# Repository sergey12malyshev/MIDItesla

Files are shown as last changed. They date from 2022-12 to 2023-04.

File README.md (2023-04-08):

# MIDItesla
MIDI Tesla Coil Controller

Программно-аппаратный проект музыкальной катушки Тесла построенной по топологии SSTC полумост. Состоит из непосредсвенно катушки Тесла, MIDI-контроллера состоящего из прерывателя bsvi на Atmega8 и микрокомпьютера Raspberry Pi 3B генерирующего MIDI мелодии.

Hardware-software project of a musical Tesla coil built on the SSTC half-bridge topology. It consists of a Tesla coil itself, a MIDI controller consisting of a bsvi interrupter on an Atmega8 and a Raspberry Pi 3B microcomputer that generates MIDI melodies.

  

 

## Программная реализация (Software) ##
Представляет собой python-скрипты выполняющиеся на Raspberry Pi B3:
* **MainMidi.py** - python скрипт генерирующий MIDI последовательности в serial-порт raspberry pi. Осуществляет переключение мелодий путём опроса кнопки.
* **lcd1602.py** - python скрипт осуществляющий вывод информации о состоянии raspberry на LCD экран 1602 (в проекте опционален).
* **runScripts.sh** - исполняемый bash скрипт необходим для запуска скриптов MainMidi.py и lcd1602notButton.py в скрытом режиме при старте системы.
Запуск скрипта runScripts.sh прописан в системном файле crontab. Для открытия файла необходимо набрать:
```bash
crontab -e
```
В файле добавить запись:
```bash
@reboot /home/pi/Desktop/runScripts.sh
```
Второй вариант запуска (вместо **runScripts.sh**) 
В crontab файле добавить запись:
```bash
@reboot python3 /home/pi/Desktop/MainMidi.py &
@reboot python3 /home/pi/Desktop/lcd1602.py &
```
## Аппаратная реализация (Hardware) ##
Cтруктурная схема всего комплекса:



Cхема электрическая принципиальная трансформатора Тесла(приведена в директории shemes):



Схема подключения MIDI OUT и схема подключения LCD 1602:

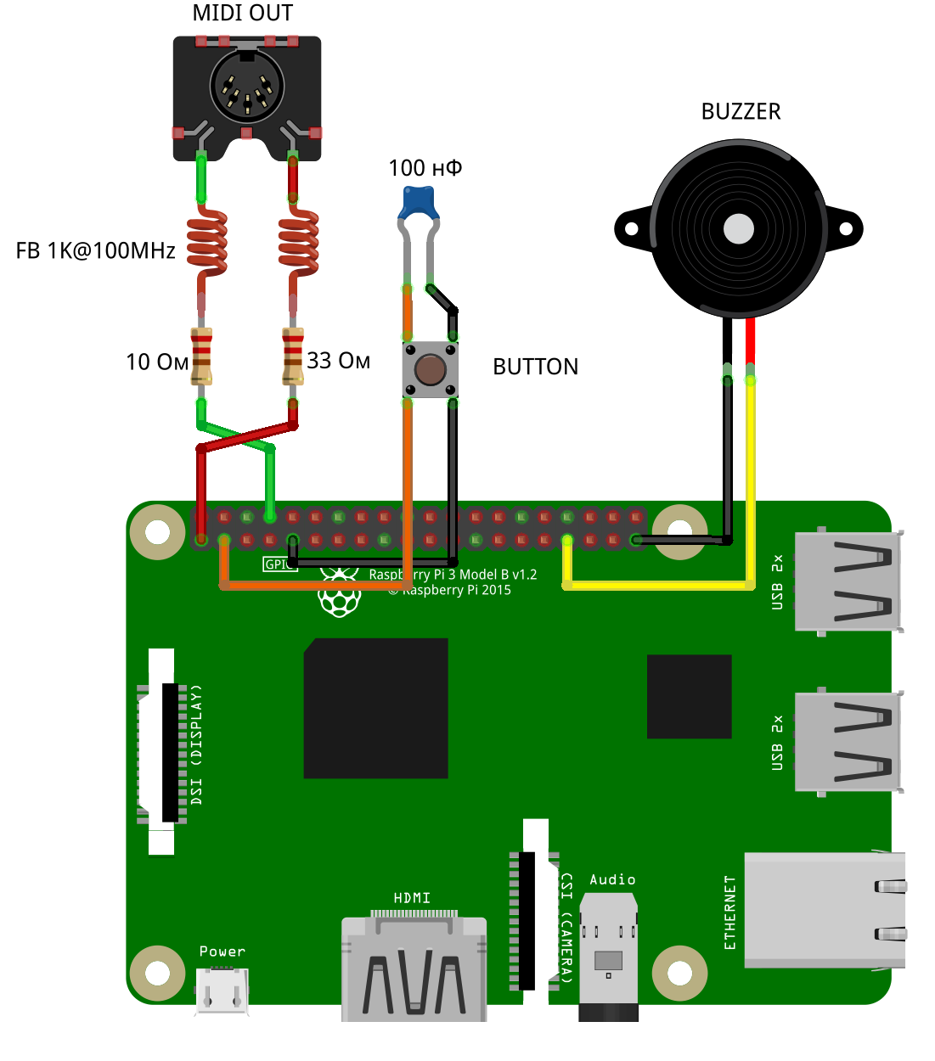
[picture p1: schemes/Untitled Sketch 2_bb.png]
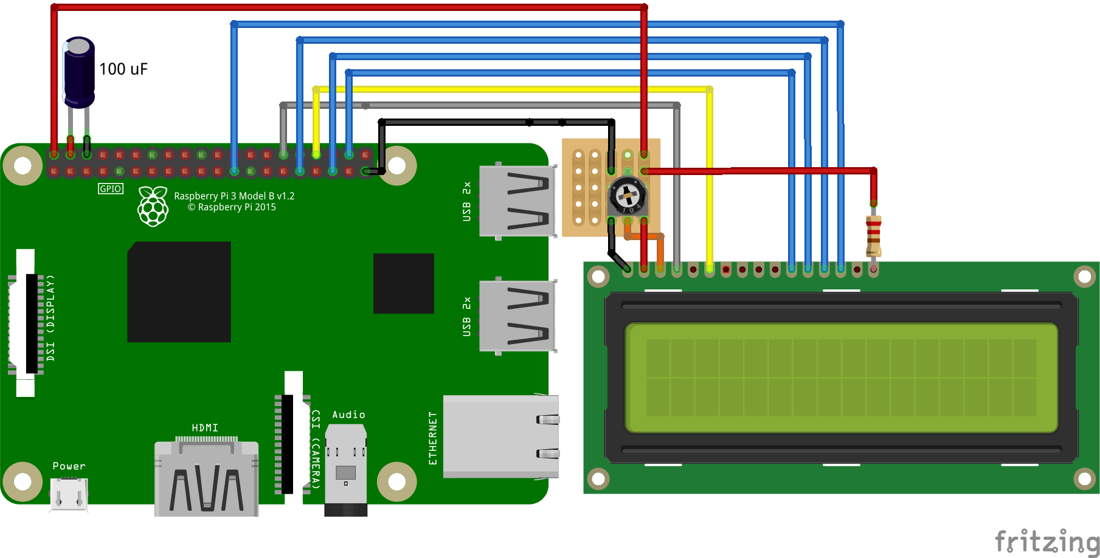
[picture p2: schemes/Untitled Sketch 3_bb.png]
     

## Создание MIDI-мелодий (Creating MIDI tunes) ##
Написание MIDI-мелодий происходит непосредственно в файле **MainMidi.py** используя функцию *playNote(note, timeOn, timeOff)*, где note - номер ноты от 36 до 71;  timeOn - время звучания в секундах; timeOff - время паузы в секундах (нет звучания). Соотношение нота-номер и нота-время приведено на рисунке:



Доступные мелодии:
- Gershon Kingsley - Popcorn
- Super Mario Song
- Mortal Kombat Theme Song
- Valces Dogs melody
- Star Wars - The Imperial March
- Mission impossible theme
- The Prodigy - Omen

## Видео работы (Demo video of work) ##
https://www.youtube.com/shorts/8kgel5WYpHc

https://youtu.be/iuJQ5y0yN18

## Полезная информация (Helpful information)
* https://bsvi.ru/preryvatel-dlya-drsstc/ - прерыватель использованный для проекта
* https://bsvi.ru/malleus-maleficarum-apgrejd/ - дизайн SSTC
* http://teslacoil.ru/katushki-tesla/tranzistornyie-katushki/polumostovaya-sstc/  - дизайн SSTC
* https://stevehv.4hv.org/SSTC5.htm  - дизайн SSTC
* https://kaizerpowerelectronics.dk/tesla-coils/sstc-design-guide/ - советы по конструкции SSTC
* https://teslafon.ru/techno/calcs - калькулятор для расчёта резонансного трансформатора
* https://www.loneoceans.com/labs/ud27/ - Universal DRSSTC Tesla Coil Driver 2.7 Rev C
* https://www.osaelectronics.com/learn/setting-up-raspberry-pi-for-midi/ - работа с midi на raspberry
* https://www.midi.org/specifications-old/item/midi-din-electrical-specification - спецификация аппаратного уровня MIDI
* http://flyback.org.ru/viewtopic.php?p=4425021#4425021 - ссылка на форум по данной конструкции
* https://pinout.xyz/ - The Raspberry Pi GPIO pinout guide

## Code style
PEP8

### Удалённое управление (Remote control)
VNC Viewer: http://wiki.amperka.ru/rpi:installation:vnc

Для автоматического запуска VNC запустить скрипт **runVNC.sh**

### Параметры резонансного трансформатора ###
Емкость тороида: 6 пФ

Индуктивность первичной обмотки: 2.94 мкГн

Индуктивность вторичной обмотки: 32901 мкГн

Количество витков вторичной обмотки: 840

Емкость вторичной обмотки: 5.8 пФ

Общая емкость вторичного контура: 11.8 пФ

Резонансная частота катушки тесла: 255.4 кГц

Доп. информация для искушенных:

Длина волны: 1565 м

Длина провода вторичной обмотки (фактическая): 290 м

Длина провода 1/4 длины волны (расчетная): 391.25 м

Процент совпадения фактической и расчетной длин: 74.1 %

Сопротивление первичной обмотки:
xL = 2 * ПИ * F * L = 2ПИ * 255.4 кГц * 2.94 мкГн = 4,73 Ом

Ток первичной обмотки:
Ipeack = U/xL = (310 В/2)/4,73 Ом =  32,8 А (выбрал ключи W45NM60 - 45 А)

### TODO
Переработать проект под чтение готовых файлов .mid

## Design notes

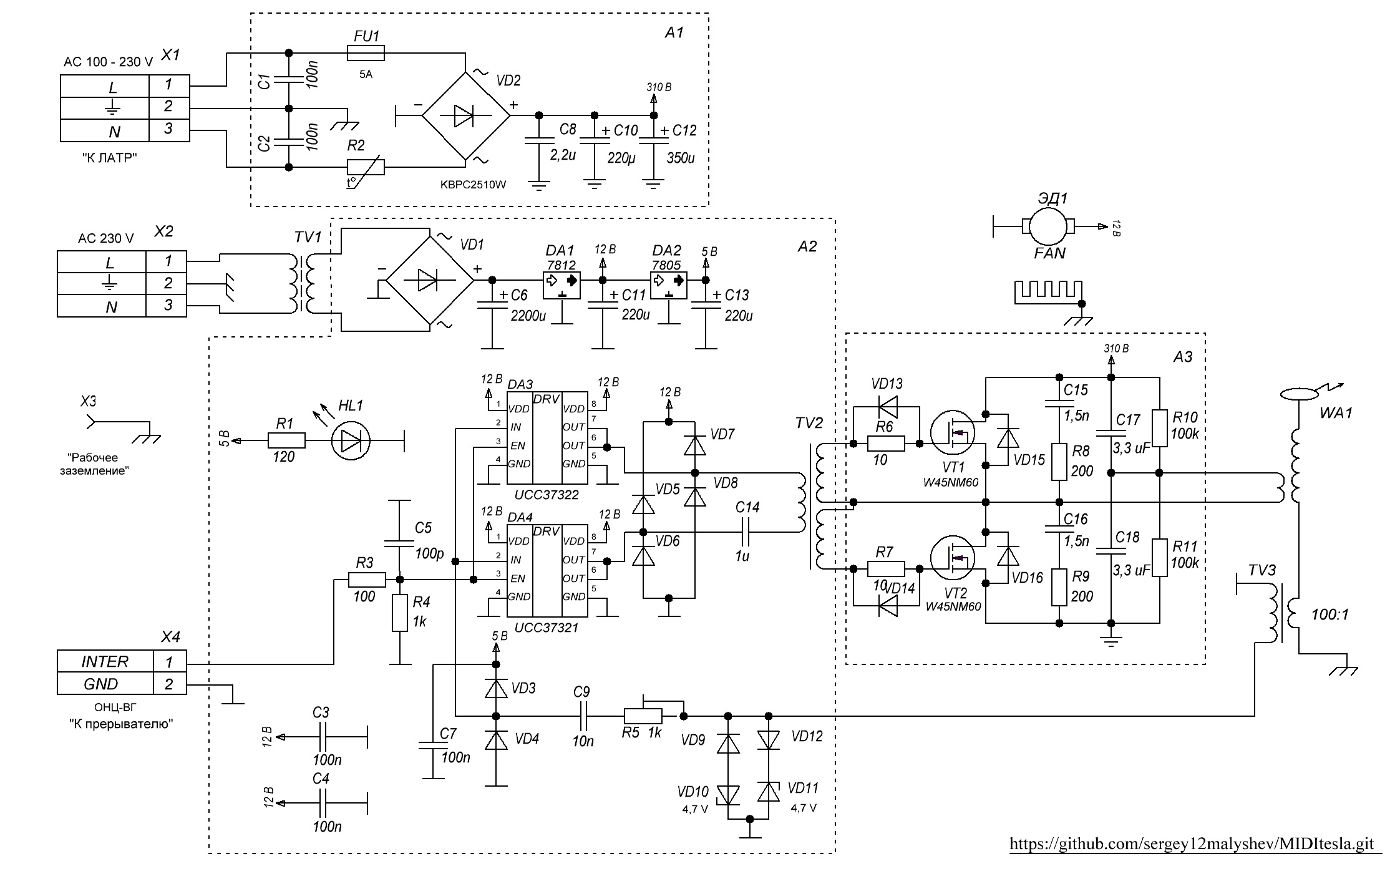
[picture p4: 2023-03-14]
images/Схема принципиальная КТ (4).jpg

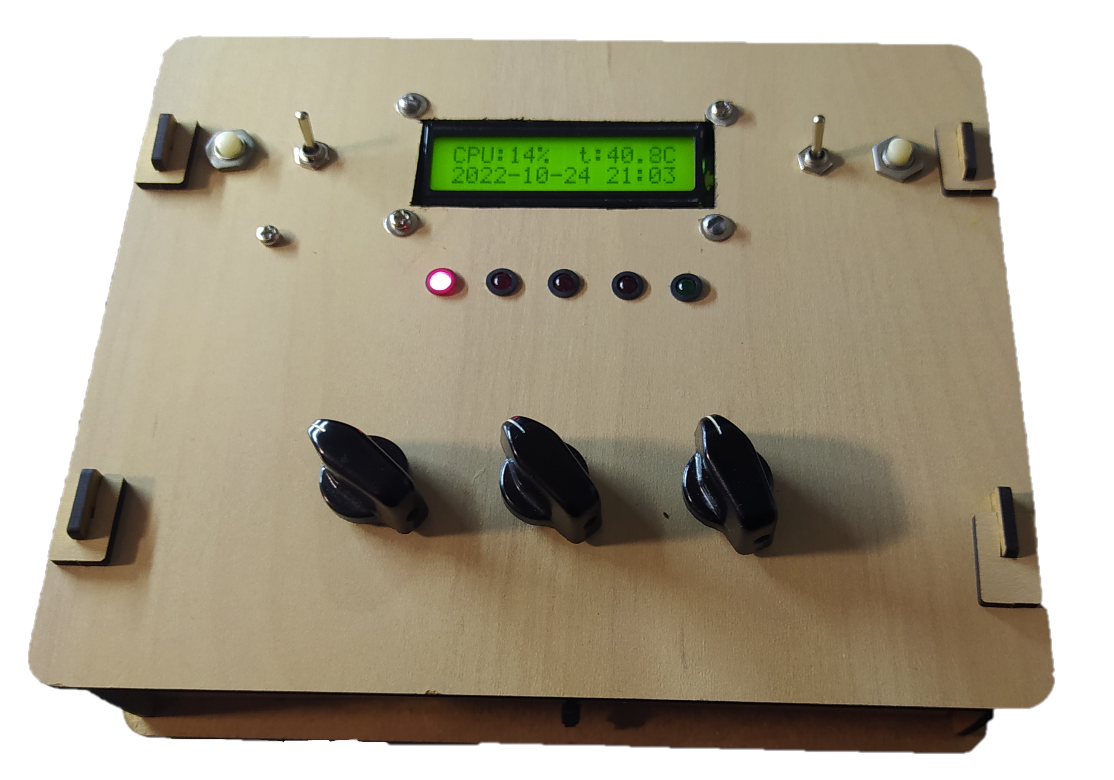
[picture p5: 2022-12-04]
images/Пульт.jpg

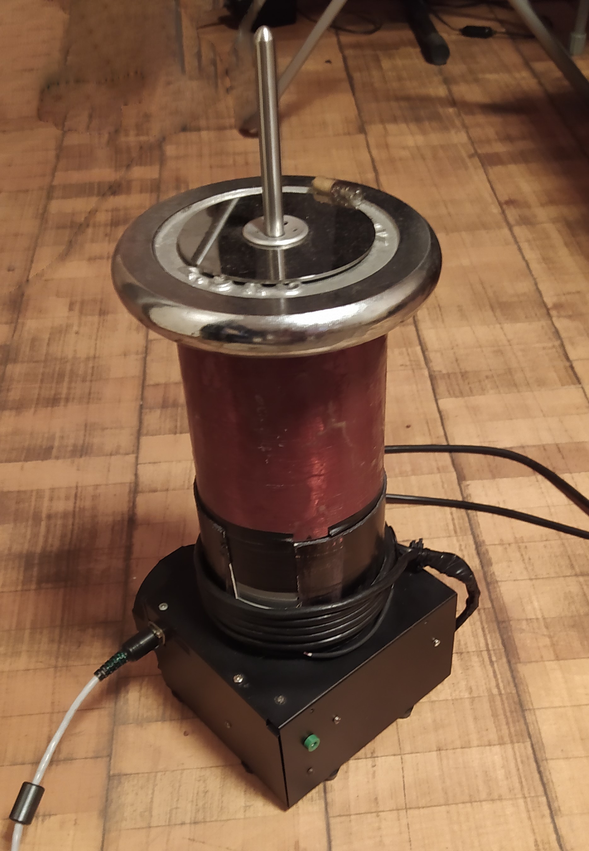
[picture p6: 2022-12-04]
images/КТ.jpg

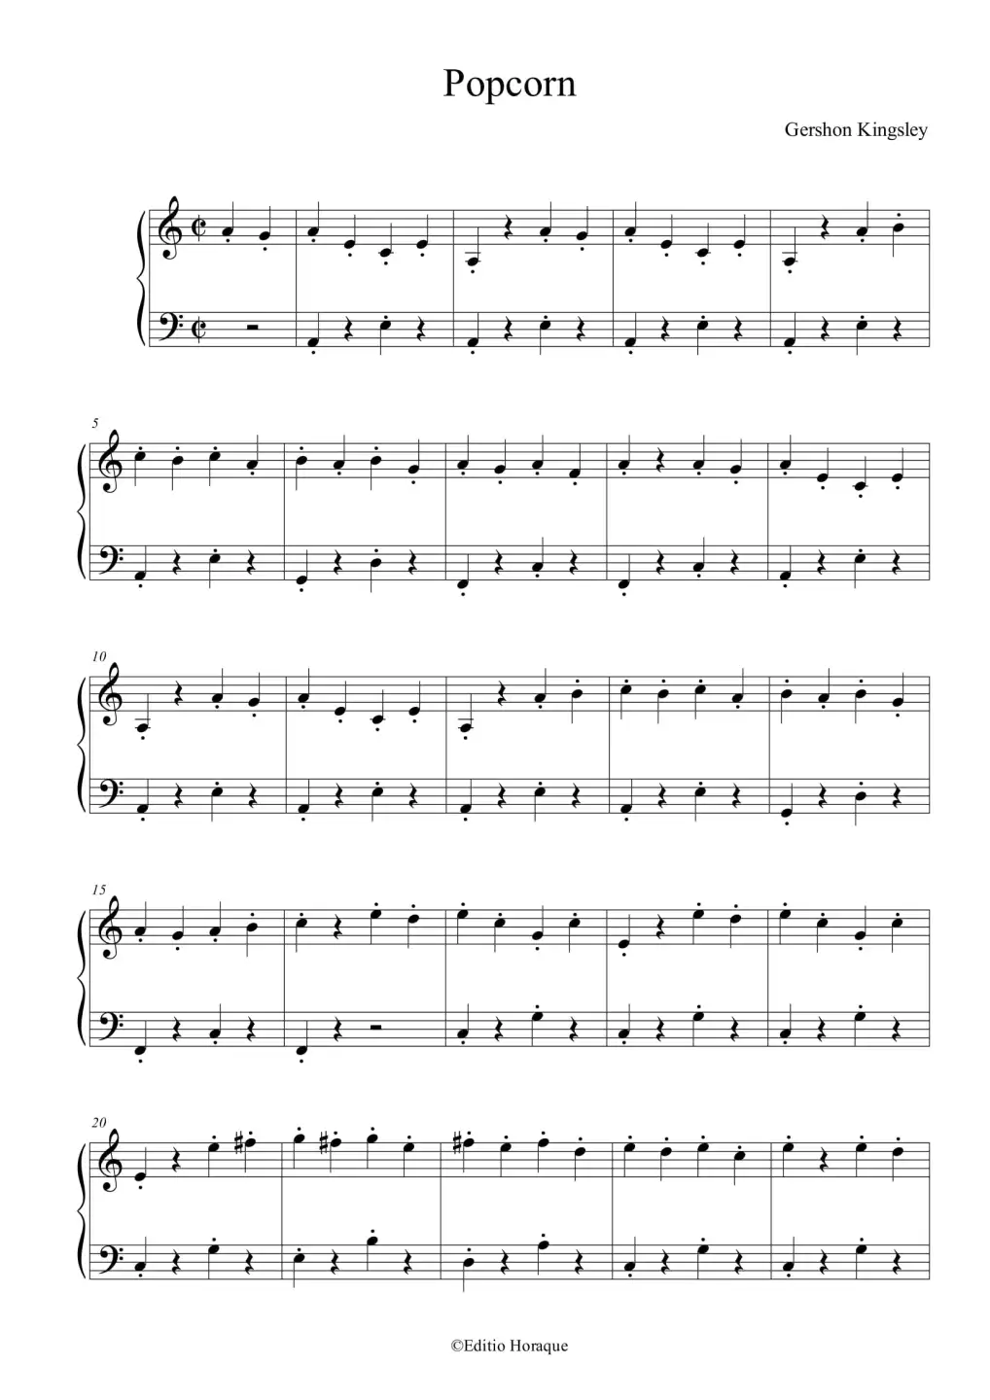
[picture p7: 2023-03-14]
schemes/Popcorn-Kingsley-Easy-Piano-1.webp

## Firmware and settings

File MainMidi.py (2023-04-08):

#!/usr/bin/env python
# -*- coding: utf-8 -*-
"""
Script that generates a MIDI signal to the serial port
Author: Malyshev S.E.(https://github.com/sergey12malyshev)
Version = '1.3.1'
Python version: 3.7.3
Platform: Raspberry PI 3 Model B v1.2
Created: 24.10.2022
Updated: see git histiry
Todo: 
"""
import serial                                     
import time                                       
import RPi.GPIO as GPIO                           
from random import randint                        

# Global variable start:
ser = serial.Serial('/dev/ttyS0', baudrate=31250)

BUZZ_PIN = 17                                                                        
BUTTON_PIN = 2                                    

CHANNEL = 2    # This represents MIDI channel
NOTE_MAX = 71
NOTE_MIN = 36
note = NOTE_MIN

flagUp = True
flagDown = False

melodyNumber = 0
oldmelodyNumber = 0

DEBUG = False                # Will set True to run debug mode
# Global variable end

GPIO.setwarnings(False)                          # Disable warnings 
GPIO.setmode(GPIO.BCM)       
GPIO.setup(BUZZ_PIN,GPIO.OUT)
GPIO.output(BUZZ_PIN, False)

GPIO.setup(BUTTON_PIN, GPIO.IN, pull_up_down=GPIO.PUD_UP) # Устанавливаем вывод в режим "вход" c подтяжкой


class Buzzer(object):
    def drive(self, timeSleep):
        GPIO.output(BUZZ_PIN, True)
        time.sleep(timeSleep)
        GPIO.output(BUZZ_PIN, False)   

class MIDI(object):  # MIDI driver interface
    def __init__(self, ch): 
        self.channel = ch
        
    def playNote(self, note: int, timeOnLocal: float, timeOffLocal: float):
        global melodyNumber, oldmelodyNumber
    
        NOTE_OFF = 8   # (0x8n) Комманда выключить ноту
        NOTE_ON = 9    # (0x9n) Комманда включить ноту
        velocity = 100 # Сила нажатия клавиши, interrupter её не воспринимает (должна быть больше 0) 
    
        def controlInputNotes():
            if note > NOTE_MAX or note < NOTE_MIN:
                print("ERROR value input note")
                buzzer.drive(0.6)
            
        controlInputNotes()    
        ser.write(bytearray([(NOTE_ON << 4) | self.channel, note, velocity]))
        time.sleep(timeOnLocal)
        ser.write(bytearray([(NOTE_OFF << 4) | self.channel, note, velocity]))
        time.sleep(timeOffLocal)
    
        if DEBUG:
            print(str(note)+' '+str(timeOnLocal)+' '+str(timeOffLocal))
    
        if oldmelodyNumber != melodyNumber:
            oldmelodyNumber = melodyNumber
            main()
            
    @staticmethod
    def resetMidi():
        SYS_RESET = 0xFF # Системное сообщение - сброс всех устройств https://ccrma.stanford.edu/~craig/articles/linuxmidi/misc/essenmidi.html
        ser.write(bytearray([SYS_RESET, 0, 0])) # Сдвига на 4 и сложения с номером канала нет т.к. системное сообщение
        time.sleep(0.1)

def button_callback(channel):
    # https://sourceforge.net/p/raspberry-gpio-python/wiki/Inputs/
    global melodyNumber
        
    buzzer.drive(0.02)
    melodyNumber += 1
    if melodyNumber == 10:
        melodyNumber = 0
    
    if DEBUG:   
        print("Button was pushed!")    
        print(f"Set melody: {melodyNumber}")
        
# Melody functions start
def popcorn_melody():
    timeOn = 0.095
    timeOff = 0.135
    
    def popcorn_1tact(timeOnLocal, timeOffLocal): 
        i = 0
        popcorn1 = [57, 55,  57, 52, 49, 52, 45]  
        while i < len(popcorn1):
            midi.playNote(popcorn1[i], timeOnLocal, timeOffLocal)
            i += 1
        
    def popcorn_2tact(timeOnLocal, timeOffLocal):
        i = 0
        popcorn2 = [57, 59, 60, 59, 60, 57,  59, 57, 59, 55,  57, 59, 57, 53,  57]  
        while i < len(popcorn2):
            midi.playNote(popcorn2[i], timeOnLocal, timeOffLocal)
            i += 1
            
    def popcorn_3tact(timeOnLocal, timeOffLocal):
        i = 0
        popcorn3 = [57, 59, 60, 59, 60, 57,  59, 57, 59, 55,  57, 55, 57, 59,  60]  
        while i < len(popcorn3):
            midi.playNote(popcorn3[i], timeOnLocal, timeOffLocal)
            i += 1
    
    def pause():
        time.sleep(timeOff * 1.5)
        
    popcorn_1tact(timeOn, timeOff)
    pause()
    popcorn_1tact(timeOn, timeOff)
    pause()
    popcorn_2tact(timeOn, timeOff)
    pause()
    popcorn_1tact(timeOn, timeOff)
    pause()
    popcorn_1tact(timeOn, timeOff)
    pause()
    popcorn_3tact(timeOn, timeOff)
    pause()
    pause()
     
def mortalKombat_melody():
    timeOn = 0.2
    timeOff = 0.07
    i = 0
    
    mortalKombat = [
        57, 57, 60, 57,  62, 57, 64, 62,   
        60, 60, 64, 60,  67, 60, 64, 60, 
        55, 55, 59, 55,  60, 55, 62, 60,   
        53, 53, 57, 53,  60, 53, 60, 59
        ]
                    
    mortalKombat2 = [
        57, 57, 57, 57, 55, 60,  57, 57, 57, 55, 52,
        57, 57, 57, 57, 55, 60,  57, 57, 57, 57, 57, 57, 57
        ]
    
    while i < len(mortalKombat):
        midi.playNote(mortalKombat[i], timeOn, timeOff)
        i += 1      
           
           
def valcesDogs_melody():
    timeOn = 0.3
    timeOff = 0.1
    i = 0
    
    valcesDogsNote = [
        65, 67, 67, 65, 67, 67,   # this 1 tact 
        64, 67, 67, 64, 67, 67,   # this 2 tact 
        62, 71, 71, 62, 71, 71,   # this 3 tact
        60, 60, 60, 60, 59, 57    # this 4 tact
        ]
    
    
    while i < len(valcesDogsNote):
        midi.playNote(valcesDogsNote[i], timeOn, timeOff)
        i += 1
      
      
def mario_melody():
    timeOn = 0.2
    timeOff = 0.07
    timeOnDiv2 = timeOn / 2
    timeOffMult2 = timeOff * 2
    
    def mario_tact1(timeOn, timeOff):
        midi.playNote(67, timeOnDiv2, timeOff)  
        midi.playNote(66, timeOnDiv2, timeOff)  
        midi.playNote(65, timeOnDiv2, timeOff)  
        midi.playNote(63, timeOnDiv2, timeOffMult2)
        midi.playNote(64, timeOnDiv2, timeOffMult2)
        
    def mario_tact2(timeOn, timeOff):
        midi.playNote(56, timeOnDiv2, timeOff)  
        midi.playNote(57, timeOnDiv2, timeOff)  
        midi.playNote(60, timeOnDiv2, timeOffMult2)
        midi.playNote(57, timeOnDiv2, timeOff)  
        midi.playNote(60, timeOnDiv2, timeOff)  
        midi.playNote(62, timeOnDiv2, timeOff * 4)
        
    def mario_tact3(timeOn, timeOff):
        midi.playNote(60, timeOn, timeOffMult2)  
        midi.playNote(55, timeOnDiv2, timeOff * 4)
        midi.playNote(52, timeOn, timeOffMult2)  
        midi.playNote(57, timeOnDiv2, timeOffMult2)
        midi.playNote(59, timeOnDiv2, timeOffMult2)
        midi.playNote(58, timeOnDiv2, timeOff)  
        midi.playNote(57, timeOn, timeOff)    

    midi.playNote(64, timeOnDiv2, timeOff)  
    midi.playNote(64, timeOnDiv2, timeOffMult2)
    midi.playNote(64, timeOnDiv2, timeOffMult2)
    midi.playNote(60, timeOnDiv2, timeOff)  
    midi.playNote(64, timeOn, timeOff)    

    midi.playNote(67, timeOn * 2, timeOffMult2)
    midi.playNote(55, timeOn * 2, timeOffMult2)

    mario_tact3(timeOn, timeOff)

    midi.playNote(55, timeOn * 3 / 4, timeOff)
    midi.playNote(64, timeOn * 3 / 4, timeOff)
    midi.playNote(67, timeOn * 3 / 4, timeOff)
    midi.playNote(69, timeOn, timeOff)    
    midi.playNote(65, timeOnDiv2, timeOff)  
    midi.playNote(67, timeOnDiv2, timeOffMult2)

    midi.playNote(64, timeOnDiv2, timeOffMult2)
    midi.playNote(60, timeOnDiv2, timeOff)  
    midi.playNote(62, timeOnDiv2, timeOff)  
    midi.playNote(59, timeOnDiv2, timeOff * 4)

    mario_tact3(timeOn, timeOff)

    midi.playNote(55, timeOn * 2 / 3, timeOff)
    midi.playNote(64, timeOn * 2 / 3, timeOff)
    midi.playNote(67, timeOn * 2 / 3, timeOff)
    midi.playNote(69, timeOn, timeOff)    
    midi.playNote(65, timeOnDiv2, timeOff)  
    midi.playNote(67, timeOnDiv2, timeOffMult2)

    midi.playNote(64, timeOnDiv2, timeOffMult2)
    midi.playNote(60, timeOnDiv2, timeOff)  
    midi.playNote(62, timeOnDiv2, timeOff)  
    midi.playNote(59, timeOnDiv2, timeOff * 8)

    mario_tact1(timeOn, timeOff)
    mario_tact2(timeOn, timeOff)
    mario_tact1(timeOn, timeOff)

    midi.playNote(60, timeOnDiv2, timeOffMult2)
    midi.playNote(60, timeOnDiv2, timeOff)  
    midi.playNote(60, timeOn, timeOff * 8)  

    mario_tact1(timeOn, timeOff)
    mario_tact2(timeOn, timeOff)

    midi.playNote(63, timeOn, timeOffMult2)  
    midi.playNote(62, timeOnDiv2, timeOff * 4)

    midi.playNote(60, timeOn, timeOff * 12) 
    
    
def imperialMarch_melody():
    timeOn = 0.35
    timeOff = 0.18
    timeOnDiv2 = timeOn / 2
    timeOnDiv4 = timeOn / 4
    timeOffDiv2 = timeOff / 2
    
    def imperialMarch_tact(timeOn, timeOff):
        midi.playNote(67, timeOn, timeOff)       
        midi.playNote(55, timeOn * 0.75, timeOffDiv2)
        midi.playNote(55, timeOnDiv4, timeOffDiv2)   
        midi.playNote(67, timeOn, timeOff)       
        midi.playNote(66, timeOn * 0.75, timeOffDiv2)
        midi.playNote(65, timeOnDiv4, timeOffDiv2)   
    
        midi.playNote(64, timeOnDiv4, timeOffDiv2)            
        midi.playNote(63, timeOnDiv4, timeOffDiv2)   
        midi.playNote(64, timeOnDiv2, timeOff * 2)   
        midi.playNote(56, timeOnDiv2, timeOffDiv2)   
        midi.playNote(61, timeOn, timeOff)       
        midi.playNote(60, timeOn * 0.75, timeOffDiv2)
        midi.playNote(59, timeOnDiv4, timeOffDiv2)   
    
        midi.playNote(58, timeOnDiv4, timeOffDiv2)          
        midi.playNote(57, timeOnDiv4, timeOffDiv2)   
        midi.playNote(58, timeOnDiv2, timeOff * 2)   
        midi.playNote(51, timeOnDiv2, timeOffDiv2)   
        midi.playNote(54, timeOn, timeOff)       
        midi.playNote(51, timeOn * 0.75, timeOffDiv2)
        midi.playNote(54, timeOnDiv4, timeOffDiv2)   
    
    def imperialMarch_tact2(timeOn, timeOff):
        midi.playNote(55, timeOn, timeOff)       
        midi.playNote(51, timeOn * 0.75, timeOffDiv2)
        midi.playNote(58, timeOnDiv4, timeOffDiv2)   
        midi.playNote(55, timeOn * 2, timeOff * 2)       
        
    # this 1 tact
    midi.playNote(55, timeOn, timeOff)       
    midi.playNote(55, timeOn, timeOff)       
    midi.playNote(55, timeOn, timeOff)       
    midi.playNote(51, timeOn * 0.75, timeOffDiv2)
    midi.playNote(58, timeOnDiv4, timeOffDiv2)   
    # this 2 tact
    imperialMarch_tact2(timeOn, timeOff)
    # this 3 tact
    midi.playNote(62, timeOn, timeOff)       
    midi.playNote(62, timeOn, timeOff)       
    midi.playNote(62, timeOn, timeOff)       
    midi.playNote(63, timeOn * 0.75, timeOffDiv2)
    midi.playNote(58, timeOnDiv4, timeOffDiv2)   
    # this 4 tact
    midi.playNote(54, timeOn, timeOff)       
    midi.playNote(51, timeOn * 0.75, timeOffDiv2)
    midi.playNote(58, timeOnDiv4, timeOffDiv2)   
    midi.playNote(55, timeOn * 2, timeOff * 2)   
    # this 5 tact and 6 tact and 7 tact
    imperialMarch_tact(timeOn, timeOff) 
    # this 8 tact
    midi.playNote(59, timeOn, timeOff)       
    midi.playNote(55, timeOn * 0.75, timeOffDiv2)
    midi.playNote(59, timeOnDiv4, timeOffDiv2)   
    midi.playNote(62, timeOn * 2, timeOff * 2)   
    # this 9 and 10 and 11 tact
    imperialMarch_tact(timeOn, timeOff) 
    # this 12 tact
    imperialMarch_tact2(timeOn, timeOff)

def missionImpossible_melody():
    timeOn = 0.25
    timeOff = 0.09
    timeOnDiv2 = timeOn / 2
    timeOffDiv2 = timeOff / 2
    i = 0
    
    def tact1():
        midi.playNote(55, timeOn, timeOff * 2)  
        midi.playNote(55, timeOnDiv2, timeOff * 4)      
        midi.playNote(58, timeOn, timeOff)    
        midi.playNote(60, timeOn, timeOff)    
    
        midi.playNote(55, timeOn, timeOff * 2)  
        midi.playNote(55, timeOnDiv2, timeOff * 4)  
        midi.playNote(53, timeOn, timeOff)    
        midi.playNote(54, timeOn, timeOff)    
    
    def solo1():
        midi.playNote(70, timeOnDiv2, timeOff)    
        midi.playNote(67, timeOnDiv2, timeOff)    
        midi.playNote(62, timeOn * 4, timeOff)    
        midi.playNote(58, timeOn, timeOff)      
        midi.playNote(60, timeOn, timeOff)      
    
    def solo2():
        midi.playNote(70, timeOnDiv2, timeOff)    
        midi.playNote(67, timeOnDiv2, timeOff)    
        midi.playNote(61, timeOn * 4, timeOff)    
        midi.playNote(53, timeOn, timeOff)      
        midi.playNote(54, timeOn, timeOff)
        
    def solo3():
        midi.playNote(70, timeOnDiv2, timeOff)    
        midi.playNote(67, timeOnDiv2, timeOff)    
        midi.playNote(60, timeOn * 4, timeOff)    
        midi.playNote(58, timeOn, timeOff)      
        midi.playNote(60, timeOn, timeOff)
        
    def solo4():
        midi.playNote(58, timeOnDiv2, timeOff)    
        midi.playNote(60, timeOn, timeOff)    
        midi.playNote(55, timeOn + (timeOnDiv2), timeOff)    
        midi.playNote(55, timeOnDiv2, timeOff * 4)  
        midi.playNote(53, timeOn, timeOff)    
        midi.playNote(54, timeOn, timeOff)  
        
    while i < 8: 
        midi.playNote(62, 0.1, 0.01)
        i += 1     
    midi.playNote(62, timeOnDiv2, timeOffDiv2)
    midi.playNote(64, timeOnDiv2, timeOffDiv2)
    midi.playNote(65, timeOnDiv2, timeOffDiv2)
    midi.playNote(66, timeOnDiv2, timeOffDiv2)
    
    tact1()
    tact1() 
    solo1()
    solo2()
    solo3()
    solo4()
    tact1()
    
    
def omen_melody():
    timeOn = 0.33
    timeOff = 0.05
    timeOnDiv2 = timeOn / 2
    timeOnDiv4 = timeOn / 4 
    
    def oneTact():
        midi.playNote(59, timeOn + (timeOnDiv2), timeOff)
        midi.playNote(70, timeOnDiv2, timeOff)
        midi.playNote(71, timeOnDiv2, timeOff)
        midi.playNote(70, timeOnDiv2, timeOff)
        midi.playNote(71, timeOnDiv2, timeOff)
        midi.playNote(70, timeOnDiv2, timeOff)
    
    def twoTact():
        midi.playNote(59, timeOnDiv2, timeOff)
        midi.playNote(65, timeOnDiv2, timeOff)
        midi.playNote(59, timeOnDiv2, timeOff)
        midi.playNote(62, timeOnDiv4, timeOff)
        midi.playNote(60, timeOnDiv4, timeOff)
         
    oneTact()
    midi.playNote(62, timeOn + (timeOnDiv2), timeOff)
    midi.playNote(61, timeOnDiv2, timeOff)
    midi.playNote(62, timeOnDiv2, timeOff)
    midi.playNote(61, timeOnDiv2, timeOff)
    midi.playNote(62, timeOnDiv2, timeOff)
    midi.playNote(66, timeOnDiv2, timeOff)
    oneTact()
    midi.playNote(59, timeOn + (timeOnDiv2), timeOff)
    midi.playNote(70, timeOnDiv2, timeOff)
    midi.playNote(71, timeOnDiv2, timeOff)
    midi.playNote(70, timeOnDiv2, timeOff)
    midi.playNote(71, timeOnDiv2, timeOff)
    midi.playNote(70, timeOnDiv2, timeOff * 1.2)
    
   
def test_ladderNotes():
    global note, flagUp, flagDown
    
    timeOn = 0.12
    timeOff = 0.07
    
    if flagUp:
        note += 1
        if (note >= NOTE_MAX):
            note = NOTE_MAX
            flagUp = False
            flagDown = True
      
    if flagDown:
        note -= 1
        if (note <= NOTE_MIN):
            note = NOTE_MIN
            flagUp = True
            flagDown = False
    
    midi.playNote(note, timeOn, timeOff)
 
 
def randomNotes():
    random_note = randint(36,71)
    midi.playNote(random_note, 0.5, 0.05)
# Melody functions end

GPIO.add_event_detect(2, GPIO.FALLING, callback=button_callback, bouncetime=250)
buzzer = Buzzer()
midi = MIDI(CHANNEL)

def main():
    
    while True:
        mN = melodyNumber 
        
        if (mN == 0):
            mortalKombat_melody()
        elif (mN == 1):
            mario_melody()
        elif (mN == 2):
            imperialMarch_melody()  
        elif (mN == 3):
            valcesDogs_melody()
        elif (mN == 4):
            popcorn_melody()
        elif (mN == 5):
            omen_melody()
        elif (mN == 6):
            missionImpossible_melody()
        elif (mN == 7):
            test_ladderNotes()
        elif (mN == 8):
            randomNotes()
        else:
            midi.resetMidi()
 
try:                                    
    main()
    
except:                                                                   
    GPIO.cleanup()                      
                                           
    print("Программа завершена, "        
          "выводы GPIO возвращены "     
          "в исходное состояние.")      
        
 

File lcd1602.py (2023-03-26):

#!/usr/bin/python
# -*- coding: utf-8 -*-
"""
The script displays on the display 1602 the system time, temperature and processor load
Authors: Malyshev S.E.(https://github.com/sergey12malyshev), 
MBTechWorks.com https://www.mbtechworks.com/projects/drive-an-lcd-16x2-display-with-raspberry-pi.html
Version = '1.2'
Python version: 2.7.16
Platform: Raspberry PI 3 Model B v1.2
Created: 2022
Updated: see git histiry
Todo: 
"""
# Pinout of the LCD:
# 1 : GND
# 2 : 5V power
# 3 : Display contrast    - Connect to middle pin potentiometer
# 4 : RS (Register Select)
# 5 : R/W (Read Write)    - Ground this pin (important)
# 6 : Enable or Strobe
# 7 : Data Bit 0          - data pin 0, 1, 2, 3 are not used
# 8 : Data Bit 1          
# 9 : Data Bit 2          
# 10: Data Bit 3          
# 11: Data Bit 4
# 12: Data Bit 5
# 13: Data Bit 6
# 14: Data Bit 7
# 15: LCD Backlight +5V
# 16: LCD Backlight GND

import RPi.GPIO as GPIO
import time
import datetime

import sys, select, termios, os
from gpiozero import LoadAverage, CPUTemperature

# GPIO to LCD mapping
LCD_RS = 7  # Pi pin 26
LCD_E = 8   # Pi pin 24
LCD_D4 = 25  # Pi pin 22
LCD_D5 = 24  # Pi pin 18
LCD_D6 = 23  # Pi pin 16
LCD_D7 = 18  # Pi pin 12

# Device constants
LCD_CHR = True  # Character mode
LCD_CMD = False  # Command mode
LCD_CHARS = 16  # Characters per line (16 max)
LCD_LINE_1 = 0x80  # LCD memory location for 1st line
LCD_LINE_2 = 0xC0  # LCD memory location 2nd line

DISPLAY_TIME_UPDATE = 0.5

def main():
    GPIO.setwarnings(False)
    GPIO.setmode(GPIO.BCM)  # Use BCM GPIO numbers
    GPIO.setup(LCD_E, GPIO.OUT)  # Set GPIO's to output mode
    GPIO.setup(LCD_RS, GPIO.OUT)
    GPIO.setup(LCD_D4, GPIO.OUT)
    GPIO.setup(LCD_D5, GPIO.OUT)
    GPIO.setup(LCD_D6, GPIO.OUT)
    GPIO.setup(LCD_D7, GPIO.OUT)

    # Initialize display
    lcd_init()

    old_minute = 0
    load_old = 0
    cpu_str_old = 0

    while True:
        
        time.sleep(DISPLAY_TIME_UPDATE)
        # and the access its now method simpler
        now = datetime.datetime.now()
        str_now = str(now)

        load = "CPU:" + str(int(LoadAverage(minutes=1).load_average * 12)) + "%"
        cpu = CPUTemperature(min_temp=50, max_temp=90)
        cpu_str = round(cpu.temperature, 1)
        cpu_str = str(cpu_str) + "C"

        print("Initial temperature: {}C".format(cpu.temperature))

        minute = now.minute
        if (load_old != load) | (old_minute != minute) | (cpu_str_old != cpu_str):
            load_old = load
            old_minute = minute
            cpu_str_old = cpu_str

        lcd_text(load + "  t:" + cpu_str, LCD_LINE_1)
        lcd_text(str_now, LCD_LINE_2)
        print("now")


# Initialize and clear display
def lcd_init():
    lcd_write(0x33, LCD_CMD)  # Initialize
    lcd_write(0x32, LCD_CMD)  # Set to 4-bit mode
    lcd_write(0x06, LCD_CMD)  # Cursor move direction
    lcd_write(0x0C, LCD_CMD)  # Turn cursor off
    lcd_write(0x28, LCD_CMD)  # 2 line display
    lcd_write(0x01, LCD_CMD)  # Clear display
    time.sleep(0.0005)  # Delay to allow commands to process


def lcd_write(bits, mode):
    # High bits
    GPIO.output(LCD_RS, mode)  # RS

    GPIO.output(LCD_D4, False)
    GPIO.output(LCD_D5, False)
    GPIO.output(LCD_D6, False)
    GPIO.output(LCD_D7, False)
    if bits & 0x10 == 0x10:
        GPIO.output(LCD_D4, True)
    if bits & 0x20 == 0x20:
        GPIO.output(LCD_D5, True)
    if bits & 0x40 == 0x40:
        GPIO.output(LCD_D6, True)
    if bits & 0x80 == 0x80:
        GPIO.output(LCD_D7, True)

    # Toggle 'Enable' pin
    lcd_toggle_enable()

    # Low bits
    GPIO.output(LCD_D4, False)
    GPIO.output(LCD_D5, False)
    GPIO.output(LCD_D6, False)
    GPIO.output(LCD_D7, False)
    if bits & 0x01 == 0x01:
        GPIO.output(LCD_D4, True)
    if bits & 0x02 == 0x02:
        GPIO.output(LCD_D5, True)
    if bits & 0x04 == 0x04:
        GPIO.output(LCD_D6, True)
    if bits & 0x08 == 0x08:
        GPIO.output(LCD_D7, True)

    lcd_toggle_enable()  # Toggle 'Enable' pin


def lcd_toggle_enable():
    time.sleep(0.0005)
    GPIO.output(LCD_E, True)
    time.sleep(0.0005)
    GPIO.output(LCD_E, False)
    time.sleep(0.0005)


def lcd_text(message, line):
    # Send text to display
    message = message.ljust(LCD_CHARS, " ")
    lcd_write(line, LCD_CMD)

    for i in range(LCD_CHARS):
        lcd_write(ord(message[i]), LCD_CHR)


# Begin program
try:
    main()

except KeyboardInterrupt:
    pass

finally:
    lcd_write(0x01, LCD_CMD)
    lcd_text("System Error!", LCD_LINE_1)
    lcd_text("Bagube", LCD_LINE_2)
    time.sleep(0.1)
    GPIO.cleanup()

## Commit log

2022-12-04 Добавление схемы Э3
2022-12-04 Добавление структурной
2022-12-04 Добавление исходников плат в формате .lay
2022-12-04 Добавление скриптов
2022-12-04 Уменьшил размер изображения
2022-12-04 эксперименты с readme.md
2022-12-04 Перераьотка структуры проекта Добавление фото
2023-01-07 Схема RPi
2023-02-24 Добавление изображений проекта
2023-02-26 Добавил доп. ссылку
2023-02-27 Добавил рандомный режим Добавил скрипт запуска VNC сервера
2023-02-27 Добавил автор+дата
2023-02-27 Добавил нотную запись
2023-02-28 Форматирование кода
2023-02-28 Установил явные булевы переменные
2023-03-02 Доработка режима выключения
2023-03-02 Рефакторинг
2023-03-03 Реф.
2023-03-04 Добавлены дополнительные мелодии
2023-03-05 Доработка
2023-03-05 Добавление проверки на соответствие дрпустимому диапазону ноты
2023-03-08 Доработка структурной схемы
2023-03-12 Запуск скрипта MainMidi.py необходим в python 3
2023-03-12 Смена принципа запуска
2023-03-12 Перевод на python 3
2023-03-13 Рефакторинг скриптов
2023-03-13 Правка README.md
2023-03-14 Добавил схему MIDI
    [Untitled Sketch 2.fzz]
2023-03-14 Схема подключения LCD
    [Untitled Sketch 3.fzz]
2023-03-16 Приведение в порядок bash скриптов
2023-03-17 Добавление новой мелодии
2023-03-17 Рефвакторинг. Изменил способ переключения между мелодиями
2023-03-17 Добавление мелодии Prodigy Omen
2023-03-18 Доработка мелодий
2023-03-18 Изменение алгоритма обработки кнопки
2023-03-26 Рефакторинг и оптимизация
2023-04-08 1. Обернул функции в классы (создал методы) 2. Добавил отладочный режим (DEBUG)
2023-04-08 Рефакторинг наименований
2023-04-08 Добавил скрипт для запуска утилиты удаленного доступа на винде
